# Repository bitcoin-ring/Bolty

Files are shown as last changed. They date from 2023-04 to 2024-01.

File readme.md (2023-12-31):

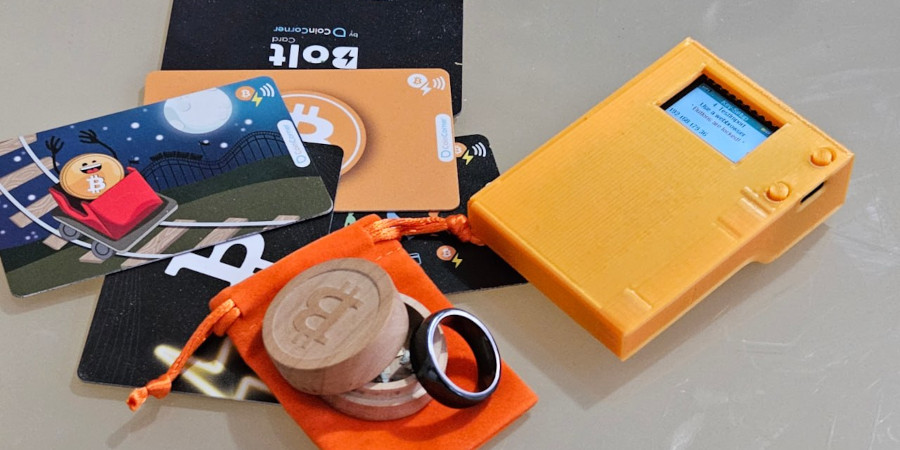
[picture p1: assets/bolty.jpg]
Bolty


# Bolty - ESP32-based BoltCard provisioning device

Bolty is an ESP32-based device with NFC capabilities designed to provision BoltCards for contactless Bitcoin Lightning Network payments. This repository contains the necessary source code, STL files for 3D printing the device enclosure, and documentation to set up and use the Bolty device.

## Features

- BoltCards provisioning for Lightning Network payments
- User-friendly web interface for device setup and management
- 3D printable enclosure design with an optional battery compartment
- Provision and deprovision BoltCards offline

## Getting Started

### Prerequisites
- LILYGO® TTGO T-Display
- An PN532 NFC module (the red square one if you want to use the enclosure),
- Basic electronics tools (e.g., soldering iron, multimeter, etc.)
- A 3D printer for printing the enclosure (optional)
- A lipo-battery (optional).

### Hardware Assembly

1. Clone this repository to your local machine:
	```shell
	git clone https://github.com/username/bolty.git
	```
2. Assemble the hardware components:

	- Solder the NFC module to the ESP32 development board.   
<table style="width: 30em;">
<tr><th>TTGO T-Display</th><th>PN532 Breakoutboard</th></tr>
<tr><td>3V</td><td>VCC</td></tr>
<tr><td>GND</td><td>GND</td></tr>
<tr><td>PIN12</td><td>MISO</td></tr>
<tr><td>PIN13</td><td>MOSI</td></tr>
<tr><td>PIN15</td><td>SS</td></tr>
<tr><td>PIN2</td><td>RSTPDN (optional)</td></tr>
<tr><td>PIN17</td><td>SCK</td></tr>
</table>
Make sure the microswitch on the NFC breakoutboard is set to SPI-configuration.

3. Navigate to the bolty/3dfiles folder and 3D print the enclosure files based on your preferences:

	- 2x Case-Button.stl
	- Case-with battery-Case.stl
	- Case-with battery-Lid.stl
	
4. Place the assembled hardware inside the 3D printed enclosure. Be careful to not put to much pressure on the tiny buttons. They rip of from the board quiet easily.

### Firmware Installation and Configuration

1. Install the required dependencies and libraries for the ESP32 development board.
	
	Arduino-IDE
	- esp32 version 1.0.6
	- Esp32 Sketch Data Upload
 	Libraries:
	- ArduinoJson version 6.20.0
	- ESPAsyncWebSrv version 1.2.6
	- Patched Adafruit_PN532_NTAG424 with ntag424 support
		from https://github.com/bitcoin-ring/Adafruit-PN532-NTAG424
	- Button2 version 1.2.0
	- qrcode version 0.0.1
	- TFT_eSPI version 2.2.20
	- ESP32-targz 1.2.0

2. Compile and upload the firmware to the ESP32 board.

3. Power on the device and wait for the display to show you a set of wifi credentials. The first startup takes a few seconds longer as the flash-memory is initialized. 
Bolty can either work in AP-mode or STA-Mode. Default is AP-Mode and the ESS-ID is always "Bolty", the password is random, also you should see an ip-adress at the bottom of the screen.

## Usage
1. Ensure your Bolty device is powered on and your computer or mobile is connected to the Wi-Fi network on the display.

2. Access the web interface of the Bolty device by navigating to the IP address displayed at the bottom part of screen using a web browser.
There are 3 menu items in the browser. Click on "SETUP" at the left side.

3. Configure your Bolty device settings.
there are multiple options.
	1. Setup a lnbit wallet, the Boltcards-extenion and a Bolt-Card configuration on a lnbits-server in one go. This is the most easiest option but it requires Bolty to be in the same wifi as your webbrowser, and your webbrowser needs a connection to the internet. Bolty will most likely have internet access in this configuration, if you dont want that use another option. Click on "SETUP"->NEW WALLET". Enter a lnbit-servers URL, enter a name for the wallet and card, modifiy the limits to your liking and present your card to the device to scan the UID of the card.
	
	2. You can import the json-string for an existing Bolt-Card created by the lnbits-Boltcards extension. This can be prepared online in a second browserwindow/tab, before you switch to the Bolty wifi. Once connected to Bolty click on "SETUP"->"IMPORT CARD". Paste the json from the prepared window into the Textarea. The button "next" turns green once the data is valid. If so click it. The name of your card and the keys should now should show up in the browser.
	3. You can also enter existing keys manually by clicking "Setup"->"EDIT CARD". Enter a Name, a the Bolt-Service url for this Bolt-Card and the keys.

4. To provision a new BoltCard, switch to the "BURN"-mode (orange). This can be done in the webbrowser or by using the lower button on the device. Now tap an NTAG424-card on the Bolty device. Make sure to keep the card presented until the process has finished. The Bolty device will write the necessary information to the NFC card, turning it into a BoltCard.

5. The BoltCard can now be used to make contactless Bitcoin Lightning Network payments with compatible payment terminals.
 
6. To wipe a BoltCard you need the corresponding keys loaded. Switch to "WIPE" mode (pink). Again, this can be done in the webbrowser or by using the lower button on the device.

## Buttons
- The upper button
	- switch on if in deepsleep mode 
	- single push switches between different card configurations. (up to five) 
	- long push toggles wifi on & off. The wifi state is saved on the eeprom, so it persist reboots.
- The lower button
	- switch between "BURN" and "WIPE"-mode. Setup is only available from the webbrowser, and if so (green upper screen) the buttons are locked.
	- long push switch off (deepsleep mode)
## Security
currently not so much, so be careful: 
 - The keys, wallet and your wifi-credentials are saved unencrypted on the eeprom of the esp32.
 - The connection between the webbrowser and Bolty is unencrypted. 
 - The backups-files you can download are unencrypted.
 - its an [esp32](https://raelize.com/blog/espressif-esp32-bypassing-encrypted-secure-boot-cve-2020-13629/)
 - anyone with a physical acccess to Bolty can produce BoltCards to spend your money

## Contributing
We welcome contributions to the Bolty project! If you'd like to contribute, please fork the repository and submit a pull request with your changes. For major changes or new features, please open an issue first to discuss your ideas with the maintainers.

## License
This project is licensed under the Apache 2.0 License. See the LICENSE file for details.

## Support and Contact
If you encounter any issues or have questions, please open an issue on GitHub.
You can also ask on https://t.me/LNBolty

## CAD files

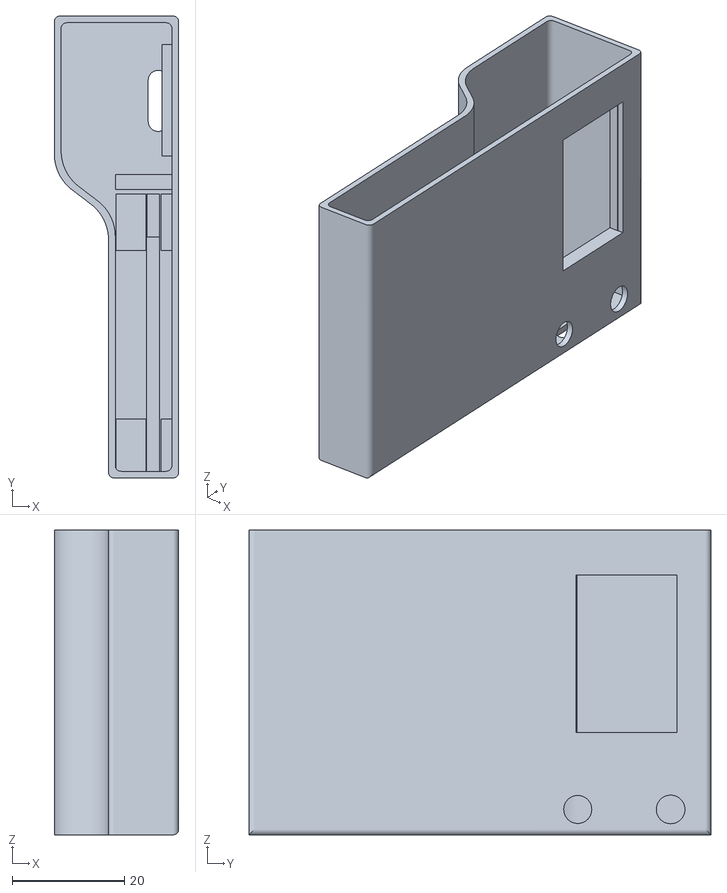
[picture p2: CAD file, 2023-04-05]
3dfiles/Case-with battery-Case.stl
22.1 x 82.2 x 54.2

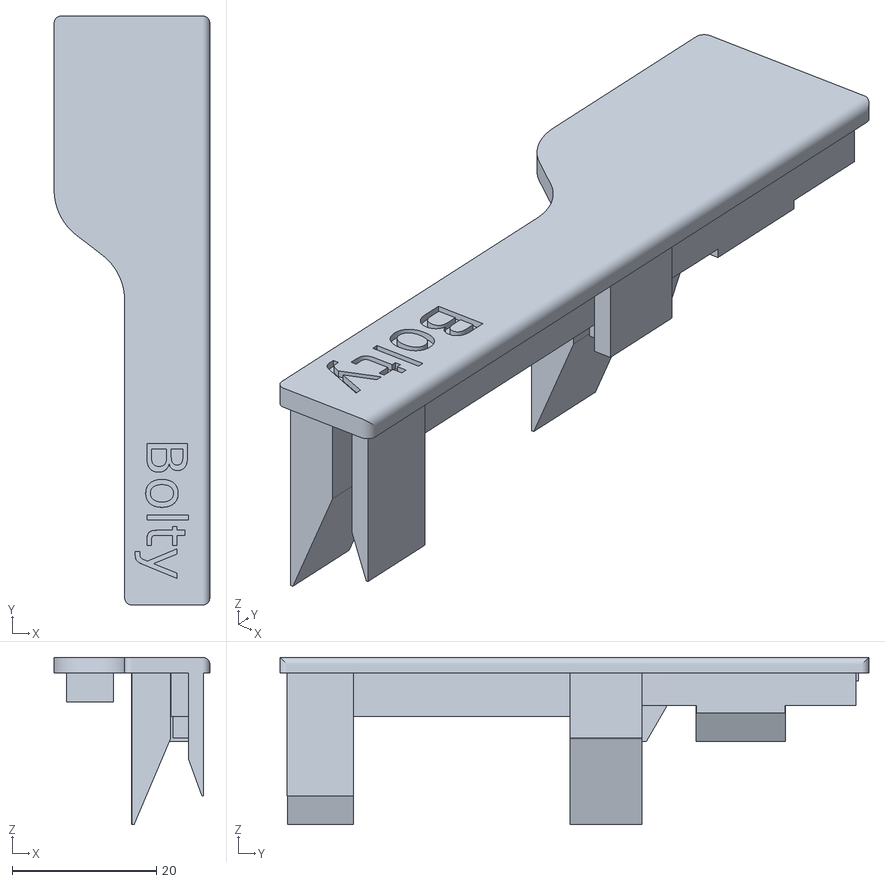
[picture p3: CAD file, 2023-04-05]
3dfiles/Case-with battery-Lid.stl
21.6 x 81.7 x 23.2

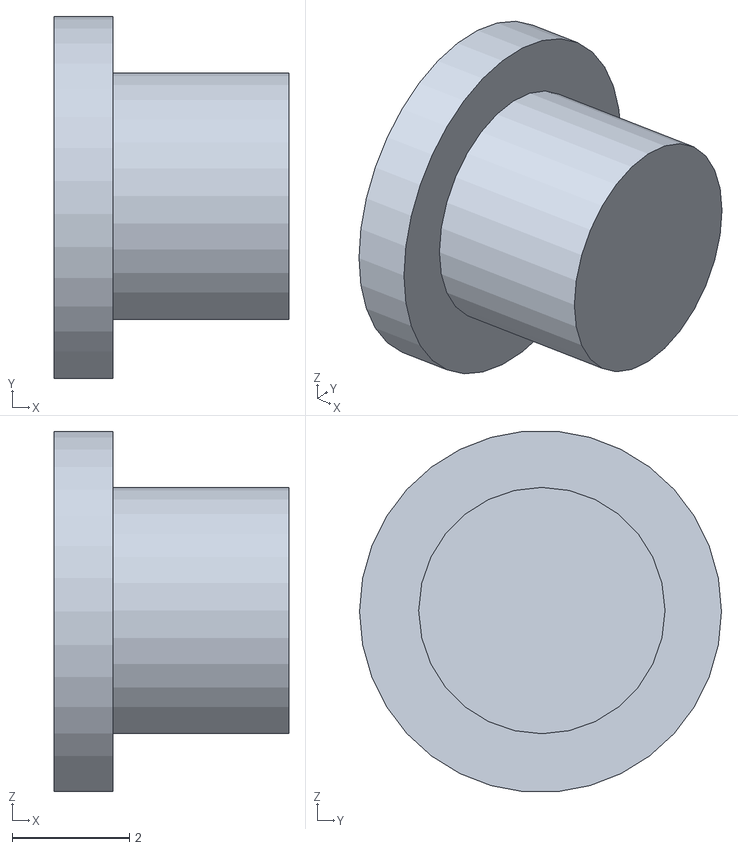
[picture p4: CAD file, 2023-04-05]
3dfiles/Case-Button.stl
4.00 x 6.17 x 6.14

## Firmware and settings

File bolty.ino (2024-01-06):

/**************************************************************************/
/*!
    @file     bolty.ino
    @author   Thilo
    https://github.com/bitcoin-ring/Bolty
    This sketch will start a wifi in AP or STA mode (WIFIMODE_*). If you want to
   use STA mode you have to enter the WIFI credentials of your existing network.
    A webserver allows to import keydata  in form of the raw json of the lnbits
   "Card key credentials" link. The keydata is saved on the eepom and should
   therefore be availabe after reboot/powerdown. The saved keydata can be used
   to provision/burn or wipe/delete ntag424 tags i.E. BoltCard, BoltRing.
    Button1:
    - śhort press: Load next boltconfiguration/keyset
    - long press: toggle wifi on/off
    Button2:
    - śhort press: Toggle between burn and wipe
    - long press: sleepmode

*/
/**************************************************************************/
#include <Arduino.h>
#include "bolt.h"
#include "gui.h"
#include <SPI.h>
#include <WiFi.h>
#include <Wire.h>
#include <esp_wifi.h>
#define DYNAMIC_JSON_DOCUMENT_SIZE 1024
#include "ArduinoJson.h"
#include "AsyncJson.h"
#include "ESPAsyncWebSrv.h"
//#include <WiFiClient.h>
#include "FS.h"
#include "SPIFFS.h"
#include <WiFiAP.h>
#define DEST_FS_USES_SPIFFS
#include <ESP32-targz.h>
#include "tarstream.h"
#include "tardata.h"

#define WIFIMODE_AP 0
#define WIFIMODE_STA 1

#define CONFIGVERSION 1

#define WIFI_AP_PASSWORD_LENGTH 8

// uncommment the next line for static wifi password
//#define WIFI_AP_PASSWORD_STATIC "wango123"

#define HTTP_CREDENTIAL_SIZE 16

//if you change this do not exceed HTTP_CREDENTIAL_SIZE-1 chars!
const char* http_default_username = "bolty";
const char* http_default_password = "bolty";

#define MAX_BOLT_DEVICES 5
char charpool[] = {
    "qweertzunopaasdfghjkyxcvbnm-?234567890QWEERTYUOPAASDFGHJKLZXCVBNM"};

// Set these to your desired credentials for WiFi AP-Mode.

char *ap_ssid = "Bolty";
#ifdef WIFI_AP_PASSWORD_STATIC
char ap_password[] = WIFI_AP_PASSWORD_STATIC;
#else
char ap_password[WIFI_AP_PASSWORD_LENGTH];
#endif

AsyncWebServer server(80);
const char *PARAM_CONFIG = "config";

// NFC Pins
#define PN532_SCK (17)
#define PN532_MOSI (13)
#define PN532_SS (15)
#define PN532_MISO (12)
#define PN532_RSTPD_N (2)
// For RSTPD_N to work i had to desolder a 10k resistor between RSTPD_N and VCC

#define APPS (3)
#define APP_KEYSETUP (0)
#define APP_BOLTBURN (1)
#define APP_BOLTWIPE (2)

#define APP_STATUS_START (0)
#define APP_STATUS_LOOP (1)
#define APP_STATUS_END (2)

BoltDevice bolt(PN532_SCK, PN532_MISO, PN532_MOSI, PN532_SS);

struct sSettings {
  char essid[33];
  char password[65];
  uint8_t wifimode;
  bool wifi_enabled;
  char http_username[HTTP_CREDENTIAL_SIZE];
  char http_password[HTTP_CREDENTIAL_SIZE];
};
sSettings mSettings;

uint8_t app_active;
int8_t app_next;
uint8_t app_status;
String SIpAddress = "Waiting for ip..";
IPAddress myIP;

uint8_t active_bolt_config;
sBoltConfig mBoltConfig;

bool signal_update_screen = false;
int signal_restart_delayed = 0;

bool bolty_hw_ready = false;

typedef void (*tAppHandler)();
typedef void (*tEvtHandler)(uint8_t btn, uint8_t evt);

struct sAppHandler {
  String app_title;
  String app_desc;
  tAppHandler app_start; // function pointer start lifecycle
  tAppHandler app_end;   // function pointer end lifecycle
  tAppHandler app_loop;  // function pointer mainloop
  uint16_t app_fgcolor;
  uint16_t app_bgcolor;
};

sAppHandler mAppHandler[APPS];

void saveSettings() {
  char path[20];
  sprintf(path, "/settings.dat");
  fs::File myFile = SPIFFS.open(path, FILE_WRITE);
  myFile.write((byte *)&mSettings, sizeof(sSettings));
  myFile.close();
}

//Extract files needed by the webserver from the data in tardata.h
void extractfiles(){
    Serial.println("Extracting files");
    Stream *HTMLTarStream = new TarStream(data_tar, (size_t) data_tar_len);
    //TarUnpacker *TARUnpacker = new TarUnpacker();
    //TARUnpacker->haltOnError(true);                                                            // stop on fail (manual restart/reset required)
    //TARUnpacker->setTarVerify(true);                                                           // true = enables health checks but slows down the overall process
    //TARUnpacker->setupFSCallbacks(targzTotalBytesFn, targzFreeBytesFn);                        // prevent the partition from exploding, recommended
    //TARGZUnpacker->setGzProgressCallback(BaseUnpacker::defaultProgressCallback ); // targzNullProgressCallback or defaultProgressCallback
    //TARUnpacker->setLoggerCallback(BaseUnpacker::targzPrintLoggerCallback);                    // gz log verbosity
    //TARUnpacker->setTarProgressCallback(BaseUnpacker::defaultProgressCallback);                // prints the untarring progress for each individual file
    //TARUnpacker->setTarStatusProgressCallback(BaseUnpacker::defaultTarStatusProgressCallback); // print the filenames as they're expanded
    //TARUnpacker->setTarMessageCallback(BaseUnpacker::targzPrintLoggerCallback);                // tar log verbosity  
    //if (!TARUnpacker->tarStreamExpander(HTMLTarStream, data_tar_len, tarGzFS, "/")){
    TarGzUnpacker *TARGZUnpacker = new TarGzUnpacker();
    TARGZUnpacker->haltOnError( true ); // stop on fail (manual restart/reset required)
    TARGZUnpacker->setTarVerify( true ); // true = enables health checks but slows down the overall process
    TARGZUnpacker->setupFSCallbacks( targzTotalBytesFn, targzFreeBytesFn ); // prevent the partition from exploding, recommended
    TARGZUnpacker->setGzProgressCallback( BaseUnpacker::defaultProgressCallback ); // targzNullProgressCallback or defaultProgressCallback
    TARGZUnpacker->setLoggerCallback( BaseUnpacker::targzPrintLoggerCallback  );    // gz log verbosity
    TARGZUnpacker->setTarProgressCallback( BaseUnpacker::defaultProgressCallback ); // prints the untarring progress for each individual file
    TARGZUnpacker->setTarStatusProgressCallback( BaseUnpacker::defaultTarStatusProgressCallback ); // print the filenames as they're expanded
    TARGZUnpacker->setTarMessageCallback( BaseUnpacker::targzPrintLoggerCallback ); // tar log verbosity
    if( !TARGZUnpacker->tarGzStreamExpander( HTMLTarStream, tarGzFS ) ) {
      Serial.println("Error while unpacking the webserver files");
      return;
    }
    //write version info
    fs::File myFile = SPIFFS.open("/fsversion.dat", FILE_WRITE);
    myFile.write((byte *) &fsversion, sizeof(fsversion));
    myFile.close();

    Serial.println("done!");
    
}

int checkFsVersion(){
  int myversion = -1;
  fs::File myFile = SPIFFS.open("/fsversion.dat", FILE_READ);
  myFile.read((byte *) &myversion, sizeof(myversion));
  myFile.close();
  Serial.println(myversion);
  return myversion;
}

void loadSettings() {
  char path[20];
  sprintf(path, "/settings.dat");
  Serial.print(path);
  if (SPIFFS.exists(path) == 1) {
    Serial.println(" found");
    fs::File myFile = SPIFFS.open(path, FILE_READ);
    myFile.read((byte *)&mSettings, sizeof(sSettings));
    myFile.close();
  } else {
    Serial.println(" not found");
    mSettings.essid[0] = 0;
    mSettings.password[0] = 0;
    mSettings.wifimode = WIFIMODE_AP;
    mSettings.wifi_enabled = 1;
    memcpy(mSettings.http_username, http_default_username, HTTP_CREDENTIAL_SIZE);
    memcpy(mSettings.http_password, http_default_password, HTTP_CREDENTIAL_SIZE);
  }
  dumpsettings();
}

void saveBoltConfig(uint8_t slot) {
  char path[20];
  sprintf(path, "/config%02x.dat", slot);
  fs::File myFile = SPIFFS.open(path, FILE_WRITE);
  myFile.write((byte *)&mBoltConfig, sizeof(sBoltConfig));
  myFile.close();
}

/*
uint8_t boltconfig_key[] = {0x00, 0x00, 0x00, 0x00, 0x00, 0x00, 0x00, 0x00,
0x00, 0x00, 0x00, 0x00, 0x00, 0x00, 0x00, 0x00}; uint8_t newlen =
bolt.nfc->ntag424_addpadding(strlen(mBoltConfig.url), 16,  (uint8_t *)
&mBoltConfig.url); Serial.println(bolt.nfc->ntag424_encrypt(boltconfig_key,
newlen, (uint8_t *) &mBoltConfig.url, testurl_enc));
Serial.println(bolt.nfc->ntag424_decrypt(boltconfig_key, newlen, testurl_enc,
testurl)); bolt.nfc->PrintHexChar(testurl, 56);
*/

void loadBoltConfig(uint8_t slot) {
  char path[20];
  sprintf(path, "/config%02x.dat", slot);
  Serial.print(path);
  Serial.println(sizeof(((sBoltConfig *)0)->url));
  memset(&mBoltConfig, 0, sizeof(sBoltConfig));
  uint8_t testurl_enc[sizeof(((sBoltConfig *)0)->url)];
  uint8_t testurl[sizeof(((sBoltConfig *)0)->url)];
  if (SPIFFS.exists(path) == 1) {
    Serial.println(" found");
    fs::File myFile = SPIFFS.open(path, FILE_READ);
    myFile.read((byte *)&mBoltConfig, sizeof(sBoltConfig));
    myFile.close();
  } else {
    Serial.println(" not found");
    strcpy(mBoltConfig.card_name, "*new*");
    mBoltConfig.url[0] = 0;
    mBoltConfig.uid[0] = 0;
    mBoltConfig.k0[0] = 0;
    mBoltConfig.k1[0] = 0;
    mBoltConfig.k2[0] = 0;
    mBoltConfig.k3[0] = 0;
    mBoltConfig.k4[0] = 0;
    mBoltConfig.wallet_name[0] = 0;
    mBoltConfig.wallet_url[0] = 0;
    mBoltConfig.wallet_host[0] = 0;
  }
  dumpconfig();
}

String exportBoltConfig() {
  String path = "/backup.dat";
  SPIFFS.remove(path);
  fs::File myFile = SPIFFS.open(path, FILE_APPEND);
  for (uint8_t i = 0; i < MAX_BOLT_DEVICES; i++) {
    loadBoltConfig(i);
    myFile.write((byte *)&mBoltConfig, sizeof(sBoltConfig));
  }
  myFile.close();
  loadBoltConfig(active_bolt_config);
  return path;
}

void importBoltConfig() {
  String path = "/backup.dat";
  fs::File myFile = SPIFFS.open(path, FILE_READ);
  for (uint8_t i = 0; i < MAX_BOLT_DEVICES; i++) {
    myFile.seek(i * sizeof(sBoltConfig));
    myFile.readBytes((char *)&mBoltConfig, sizeof(sBoltConfig));
    // loadBoltConfig(i);
    saveBoltConfig(i);
    dumpconfig();
  }
  myFile.close();
  loadBoltConfig(active_bolt_config);
}

// Keysetup
void app_keysetup_start() { Serial.println("app_KEYSETUP_start"); }

long lasttime = 0;
String default_app_message = "* Buttons are locked! *";
String app_message = default_app_message;
void app_keysetup_loop() {
  if ((millis() - lasttime) > 200) {
    lasttime = millis();
    tft.setFreeFont(&FreeSans9pt7b);
    tft.setTextColor(APPRED);
    if (bolty_hw_ready){
      bool success = bolt.scanUID();
      app_message = bolt.getScannedUid();
    }
    if (app_message == "") {
      app_message = default_app_message;
    }
    tft.fillRect(0, -3 + (3 * 23), tft.width(), 21, APPWHITE);
    displayTextCentered(-3 + (4 * 21), app_message);
  }
  if (!mSettings.wifi_enabled) {
    app_next = APP_BOLTBURN;
  }
  delay(50);
}

String web_keysetup_processor(const String &var) {
  // Serial.println("web_keysetup_loop");
  if (var == "wallet_name")
    return mBoltConfig.wallet_name;
  if (var == "wallet_host")
    return mBoltConfig.wallet_host;
  if (var == "wallet_url")
    return mBoltConfig.wallet_url;
  if (var == "wallet_link")
    return mBoltConfig.wallet_url;
  if (var == "uid")
    return mBoltConfig.uid;
  return processor_default(var);
}

void app_keysetup_end() { Serial.println("app_KEYSETUP_end"); }

// Ringsetup
void APP_BOLTBURN_start() { Serial.println("APP_BOLTBURN_start"); }

uint32_t previousMillis;
uint32_t Interval = 100;

void APP_BOLTBURN_loop() {
  // Serial.println("APP_BOLTBURN_loop");
  // set the keys
  if (millis() - previousMillis < Interval) {
    return;
  }
  previousMillis = millis();
  Interval = 100;
  if (bolty_hw_ready){
    bolt.setDefautKeysCur();
    bolt.setNewKey(mBoltConfig.k0, 0);
    bolt.setNewKey(mBoltConfig.k1, 1);
    bolt.setNewKey(mBoltConfig.k2, 2);
    bolt.setNewKey(mBoltConfig.k3, 3);
    bolt.setNewKey(mBoltConfig.k4, 4);
    String lnurl = String(mBoltConfig.url);
    uint8_t burn_result = bolt.burn(lnurl);
    if (burn_result != JOBSTATUS_WAITING) {
      previousMillis = millis();
      Interval = 3000;
      dumpconfig();
    }
  }
  else{
    tft.setFreeFont(&FreeSans9pt7b);
    tft.setTextColor(APPRED);
    tft.fillRect(0, -3 + (3 * 23), tft.width(), 21, APPWHITE);
    displayTextCentered(-3 + (4 * 21), "nfc hw not ready");
  }
}


String shortenkeys(const String &var){
  return var.substring(0,3) + "*************";
}

String processor_default(const String &var){
  if (var == "cnn")
    return String(active_bolt_config + 1).c_str();
  if (var == "cn")
    return mBoltConfig.card_name;
  if (var == "url")
    return mBoltConfig.url;
  if (var == "ks0")
    return shortenkeys(mBoltConfig.k0);
  if (var == "ks1")
    return shortenkeys(mBoltConfig.k1);
  if (var == "ks2")
    return shortenkeys(mBoltConfig.k2);
  if (var == "ks3")
    return shortenkeys(mBoltConfig.k3);
  if (var == "ks4")
    return shortenkeys(mBoltConfig.k4);
  if (var == "k0")
    return mBoltConfig.k0;
  if (var == "k1")
    return mBoltConfig.k1;
  if (var == "k2")
    return mBoltConfig.k2;
  if (var == "k3")
    return mBoltConfig.k3;
  if (var == "k4")
    return mBoltConfig.k4;
  if (var == "wifista")
        return String(mSettings.wifimode);
  if (var == "essid")
        if (mSettings.wifimode == WIFIMODE_STA)
                return String(mSettings.essid);
  /*if (var == "essid")
    //if (mSettings.wifimode == WIFIMODE_STA)
    return String(mSettings.essid);
   */
  return String();
}

String web_burn_processor(const String &var) {
  Serial.println("web_ringsetup_loop");
  if (var == "job")
    return "Burn";
  return processor_default(var);
}
void APP_BOLTBURN_end() { Serial.println("APP_BOLTBURN_end"); }
// Ringsetup
void APP_BOLTWIPE_start() { Serial.println("APP_BOLTWIPE_start"); }

void APP_BOLTWIPE_loop() {
  // Serial.println("APP_BOLTWIPE_loop");
  if (millis() - previousMillis < Interval) {
    return;
  }
  previousMillis = millis();
  Interval = 100;
  if (bolty_hw_ready){
    bolt.setDefautKeysNew();
    bolt.setCurKey(mBoltConfig.k0, 0);
    bolt.setCurKey(mBoltConfig.k1, 1);
    bolt.setCurKey(mBoltConfig.k2, 2);
    bolt.setCurKey(mBoltConfig.k3, 3);
    bolt.setCurKey(mBoltConfig.k4, 4);
    uint8_t wipe_result = bolt.wipe();
    if (wipe_result != JOBSTATUS_WAITING) {
      previousMillis = millis();
      Interval = 3000;
      dumpconfig();
    }
  }
  else{
    tft.setFreeFont(&FreeSans9pt7b);
    tft.setTextColor(APPRED);
    tft.fillRect(0, -3 + (3 * 23), tft.width(), 21, APPWHITE);
    displayTextCentered(-3 + (4 * 21), "nfc hw not ready");
  }
}

String web_ringwipe_processor(const String &var) {
  Serial.println("web_ringwipe_loop");
  if (var == "job")
    return "Wipe";
  return processor_default(var);
}
void APP_BOLTWIPE_end() { Serial.println("APP_BOLTWIPE_end"); }

uint8_t lineh = 21;
void update_screen() {
  tft.fillScreen(fromrgb(0xed, 0xef, 0xf2));
  int8_t ofs = -3;
  tft.fillRect(0, 0, tft.width(), 23, mAppHandler[app_active].app_bgcolor);
  draw_battery(true);
  draw_wifi(mSettings.wifi_enabled);

  tft.setFreeFont(&FreeSans9pt7b);
  tft.setTextColor(APPWHITE);
  displayTextCentered(ofs + (1 * lineh), mAppHandler[app_active].app_title);
  tft.setTextColor(mAppHandler[app_active].app_fgcolor);
  displayTextCentered(ofs + (2 * lineh), String(active_bolt_config + 1) + ". " +
                                             mBoltConfig.card_name);
  displayTextCentered(ofs + (3 * lineh), mAppHandler[app_active].app_desc);
  if (mSettings.wifi_enabled) {
    // displayTextLeft(ofs + (4 * lineh), "WiFi");
    if (mSettings.wifimode == WIFIMODE_AP) {
      displayTextLeft(ofs + (5 * lineh),
                      "WiFi " + String(ap_ssid) + ":" + String(ap_password));
    }
    SIpAddress = getIpAddress();
    displayTextLeft(ofs + (6 * lineh), SIpAddress);
  }
  signal_update_screen = false;
}

void handle_events() {
  // Button 0 short clicky = next keyset
  if ((sharedvars.appbuttons[0] == 1) && (app_active != APP_KEYSETUP)) {
    // we dont want to interrupt anything done with keyysetup
    active_bolt_config += 1;
    if (active_bolt_config >= MAX_BOLT_DEVICES) {
      active_bolt_config = 0;
    }
    loadBoltConfig(active_bolt_config);
    signal_update_screen = true;
  }
  // Button 1 short clicky = next app
  if ((sharedvars.appbuttons[1] == 1) && (app_active != APP_KEYSETUP)) {
    // we dont want to interrupt anything done with keyysetup
    app_next = app_active + 1;
    if (app_next > APPS - 1) {
      app_next = 1;
    }
  }
  // Button 0 long clicky =
  if (sharedvars.appbuttons[0] == 2) {
    wifi_toogle();
    signal_update_screen = true;
  }
  // Button 1 long clicky =
  if (sharedvars.appbuttons[1] == 2) {
    nfc_stop();
    esp_sleep_enable_ext0_wakeup(GPIO_NUM_35, 0); // 1 = High, 0 = Low
    esp_deep_sleep_start();
  }
  // Button 0 double clicky =
  if (sharedvars.appbuttons[0] == 3) {
    Serial.println("double click btn0");
    String wurl =
        String(mBoltConfig.wallet_host) + "?" + String(mBoltConfig.wallet_url);
    Serial.println(wurl);
    // displayQR(wurl);
  }
  // Button 1 duoble clicky =
  if (sharedvars.appbuttons[1] == 3) {
    Serial.println("double click btn1");
  }
  // reset button events
  sharedvars.appbuttons[0] = 0;
  sharedvars.appbuttons[1] = 0;
}

void app_stateengine() {
  handle_events();
  if (signal_update_screen){
      update_screen();
  }
  if (signal_restart_delayed > 0){
    delay(3000);
    ESP.restart();
  }
  if (app_next >= APPS)
    app_next = 0;
  // do not switch to keysetup using buttons
  if (app_next < 0)
    app_next = APPS - 1;

  if (app_active != app_next) {
    Serial.print("start: current app:");
    Serial.println(app_active);
    Serial.print("switching to app:");
    Serial.println(app_next);
    app_status = APP_STATUS_END;
  }
  if (app_status == APP_STATUS_START) {
    (*mAppHandler[app_active].app_start)();
    app_status = APP_STATUS_LOOP;
    update_screen();
  }
  if (app_status == APP_STATUS_LOOP) {
    draw_battery();
    draw_wifi(mSettings.wifi_enabled);
    (*mAppHandler[app_active].app_loop)();
  }
  if (app_status == APP_STATUS_END) {
    Serial.print("end: ending app:");
    Serial.println(app_active);
    Serial.print("end: activating app:");
    Serial.println(app_next);
    (*mAppHandler[app_active].app_end)();
    app_active = app_next;
    app_status = APP_STATUS_START;
  }
}

void dumpconfig() {
  Serial.println(mBoltConfig.wallet_name);
  Serial.println(mBoltConfig.wallet_host);
  Serial.println(mBoltConfig.wallet_url);
  Serial.println(mBoltConfig.uid);
  Serial.println(mBoltConfig.card_name);
  Serial.println(mBoltConfig.url);
  Serial.println(mBoltConfig.k0);
  Serial.println(mBoltConfig.k1);
  Serial.println(mBoltConfig.k2);
  Serial.println(mBoltConfig.k3);
  Serial.println(mBoltConfig.k4);
}

void dumpsettings() {
  Serial.println(mSettings.wifimode);
  Serial.println(mSettings.essid);
  Serial.println(mSettings.password);
  Serial.println(mSettings.wifi_enabled);
  Serial.println(mSettings.http_username);
  Serial.println(mSettings.http_password);
}

void checkparams(AsyncWebServerRequest *request) {
  if (request->hasParam("d")) {
    AsyncWebParameter *p = request->getParam("d");
    Serial.println("got d param");
    Serial.println(p->value().c_str());
    if (p->value() == "p") {
      active_bolt_config =
          constrain((active_bolt_config - 1), 0, MAX_BOLT_DEVICES - 1);
    }
    if (p->value() == "n") {
      active_bolt_config =
          constrain((active_bolt_config + 1), 0, MAX_BOLT_DEVICES - 1);
    }
    loadBoltConfig(active_bolt_config);
    signal_update_screen = true;
  }
  Serial.println(active_bolt_config);
}

void empty() {
  //
}

void randomchar(char *outbuf, uint8_t count) {
  for (uint8_t i = 0; i < count; i++) {
    Serial.print(i);
    Serial.print(":");
    outbuf[i] = charpool[random(0, 63)];
    Serial.println(outbuf[i]);
  }
  outbuf[count] = 0;
}

String getIpAddress() {
  if (mSettings.wifimode == WIFIMODE_AP)
    myIP = WiFi.softAPIP();
  if (mSettings.wifimode == WIFIMODE_STA)
    myIP = WiFi.localIP();
  return myIP.toString();
}

void wifi_start() {
  // if we have credentials try connecting. WIFIMODE_STA will fallback to
  // mSettings.wifimode == WIFIMODE_AP
  if ((mSettings.essid != "") && (mSettings.password != "")) {
    mSettings.wifimode = WIFIMODE_STA;
  }
  if (mSettings.wifimode == WIFIMODE_AP) {
#ifndef WIFI_AP_PASSWORD_STATIC
    randomchar(ap_password, sizeof(ap_password));
#endif
    WiFi.softAP(ap_ssid, ap_password);
    myIP = WiFi.softAPIP();
  }

  uint8_t connect_count = 0;
  if (mSettings.wifimode == WIFIMODE_STA) {
    WiFi.begin(mSettings.essid, mSettings.password);
    while (WiFi.status() != WL_CONNECTED) {
      delay(500);
      connect_count++;
      Serial.println("Connecting to WiFi..");
      // fall back to AP mode if we cannot connect for 10 seconds
      if (connect_count > 10) {
        Serial.println("Cannot connect to Network. Fallback to AP-Mode.");
        wifi_stop();
        delay(50);
        mSettings.wifimode = WIFIMODE_AP;
#ifndef WIFI_AP_PASSWORD_STATIC
        randomchar(ap_password, sizeof(ap_password));
#endif
        WiFi.softAP(ap_ssid, ap_password);
        myIP = WiFi.softAPIP();
        break;
      }
    }
    // still STA mode? then we should be connected by now!
    if (mSettings.wifimode == WIFIMODE_STA) {
      myIP = WiFi.localIP();
    }
  }
  if (!mSettings.wifi_enabled) {
    mSettings.wifi_enabled = true;
    saveSettings();
    //set wifimode  after savesettings. we dont want to persist it if we fallback to apmode.
    if ((mSettings.wifimode == WIFIMODE_STA) && (connect_count <= 10)) {
      mSettings.wifimode = WIFIMODE_AP;
    }
  }
  server.begin();
}

void wifi_stop() {
  server.end();
  WiFi.mode(WIFI_STA);
  WiFi.disconnect();
  esp_wifi_stop();
  Serial.println("WIFI: Disconnected");
  delay(100);
  WiFi.mode(WIFI_OFF);
  delay(100);
  if (mSettings.wifi_enabled) {
    mSettings.wifi_enabled = false;
    saveSettings();
  }
}

void wifi_toogle() {
  if (mSettings.wifi_enabled) {
    wifi_stop();
  } else {
    wifi_start();
  }
}

void nfc_start() {
  Serial.println("switching nfc on");
  digitalWrite(PN532_RSTPD_N, HIGH);
}
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
void loop(void) {

  app_stateengine();

  delay(100);
}

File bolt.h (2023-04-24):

#ifndef BOLT_H
#define BOLT_H

//#define NTAG424DEBUG

#include "gui.h"
#include <Adafruit_PN532_NTAG424.h>
#include <SPI.h>
#include <Wire.h>

#define JOBSTATUS_IDLE 0
#define JOBSTATUS_WAITING 1
#define JOBSTATUS_PROVISIONING 2
#define JOBSTATUS_WIPING 3
#define JOBSTATUS_DONE 4
#define JOBSTATUS_ERROR 5

String boltstatustext[6] = {
    "idle",          "waiting for nfc-tag..",  "provisioning data..",
    "wiping data..", "done - remove the card", "error",
};

struct sBoltConfig {
  char card_name[50];
  char wallet_host[50];
  char wallet_name[256];
  char wallet_url[256];
  char url[256];
  char uid[17];
  char k0[33];
  char k1[33];
  char k2[33];
  char k3[33];
  char k4[33];
};

String convertIntToHex(uint8_t *input, uint8_t len) {
  String ret = "";
  for (uint8_t i = 0; i < len; i++) {
    char hexChar[2];
    sprintf(hexChar, "%02X", input[i]);
    ret += hexChar;
  }
  return ret;
}

uint8_t convertCharToHex(char ch) {
  uint8_t returnType;
  switch (toupper(ch)) {
  case '0':
    returnType = 0;
    break;
  case '1':
    returnType = 1;
    break;
  case '2':
    returnType = 2;
    break;
  case '3':
    returnType = 3;
    break;
  case '4':
    returnType = 4;
    break;
  case '5':
    returnType = 5;
    break;
  case '6':
    returnType = 6;
    break;
  case '7':
    returnType = 7;
    break;
  case '8':
    returnType = 8;
    break;
  case '9':
    returnType = 9;
    break;
  case 'A':
    returnType = 10;
    break;
  case 'B':
    returnType = 11;
    break;
  case 'C':
    returnType = 12;
    break;
  case 'D':
    returnType = 13;
    break;
  case 'E':
    returnType = 14;
    break;
  case 'F':
    returnType = 15;
    break;
  default:
    returnType = 0;
    break;
  }
  return returnType;
}

class BoltDevice {

public: // Access specifier
  Adafruit_PN532 *nfc = NULL;
  uint8_t key_cur[5][16] = {{0x00, 0x00, 0x00, 0x00, 0x00, 0x00, 0x00, 0x00,
                             0x00, 0x00, 0x00, 0x00, 0x00, 0x00, 0x00, 0x00},
                            {0x00, 0x00, 0x00, 0x00, 0x00, 0x00, 0x00, 0x00,
                             0x00, 0x00, 0x00, 0x00, 0x00, 0x00, 0x00, 0x00},
                            {0x00, 0x00, 0x00, 0x00, 0x00, 0x00, 0x00, 0x00,
                             0x00, 0x00, 0x00, 0x00, 0x00, 0x00, 0x00, 0x00},
                            {0x00, 0x00, 0x00, 0x00, 0x00, 0x00, 0x00, 0x00,
                             0x00, 0x00, 0x00, 0x00, 0x00, 0x00, 0x00, 0x00},
                            {0x00, 0x00, 0x00, 0x00, 0x00, 0x00, 0x00, 0x00,
                             0x00, 0x00, 0x00, 0x00, 0x00, 0x00, 0x00, 0x00}};
  uint8_t key_new[5][16] = {{0x00, 0x00, 0x00, 0x00, 0x00, 0x00, 0x00, 0x00,
                             0x00, 0x00, 0x00, 0x00, 0x00, 0x00, 0x00, 0x00},
                            {0x00, 0x00, 0x00, 0x00, 0x00, 0x00, 0x00, 0x00,
                             0x00, 0x00, 0x00, 0x00, 0x00, 0x00, 0x00, 0x00},
                            {0x00, 0x00, 0x00, 0x00, 0x00, 0x00, 0x00, 0x00,
                             0x00, 0x00, 0x00, 0x00, 0x00, 0x00, 0x00, 0x00},
                            {0x00, 0x00, 0x00, 0x00, 0x00, 0x00, 0x00, 0x00,
                             0x00, 0x00, 0x00, 0x00, 0x00, 0x00, 0x00, 0x00},
                            {0x00, 0x00, 0x00, 0x00, 0x00, 0x00, 0x00, 0x00,
                             0x00, 0x00, 0x00, 0x00, 0x00, 0x00, 0x00, 0x00}};

  uint8_t job_status; // 0=idle; 1=wait for tag; 2=busy provisioning;3=busy wipe
  uint8_t job_perc;
  uint8_t job_ok;
  String last_scanned_uid;

  BoltDevice(uint8_t SCK, uint8_t MISO, uint8_t MOSI,
             uint8_t SS) { // Constructor
    nfc = new Adafruit_PN532(SCK, MISO, MOSI, SS);
  }

  void setDefautKeys(uint8_t keys[5][16]) {
    for (int i = 0; i < 5; i++) {
      memset((void *)(keys[i]), 0, 16);
    }
  }

  void setDefautKeysNew() { setDefautKeys(key_new); }
  void setDefautKeysCur() { setDefautKeys(key_cur); }

  void setKey(uint8_t keys[16], String key) {
    for (int i = 0; i < key.length(); i += 2) {
      uint8_t ki = (i / 2);
      uint8_t upper = (convertCharToHex(key[i]) << 4);
      uint8_t lower = (convertCharToHex(key[i + 1]));
      keys[ki] = (upper | lower);
    }
    // Serial.print("Key Set: ");
    // Serial.println(key);
  }

  void setNewKey(String key, uint8_t keyno) { setKey(key_new[keyno], key); }

  void setCurKey(String key, uint8_t keyno) { setKey(key_cur[keyno], key); }

  bool begin() {

    nfc->begin();

    uint32_t versiondata = nfc->getFirmwareVersion();
    if (!versiondata) {
      Serial.print("Didn't find PN53x board");
      return false;
        ; // halt
    }
    // Got ok data, print it out!
    Serial.print("Found chip PN53x");
    Serial.println((versiondata >> 24) & 0xFF, HEX);
    Serial.print("Firmware ver. ");
    Serial.print((versiondata >> 16) & 0xFF, DEC);
    Serial.print('.');
    Serial.println((versiondata >> 8) & 0xFF, DEC);

    // configure board to read RFID tags
    nfc->SAMConfig();

    Serial.println("NFC Ready...");
    return true;
  }

  String get_job_status() { return boltstatustext[job_status]; }

  uint8_t get_job_perc() { return job_perc; }

  uint8_t get_job_status_id() { return job_status; }

  void set_job_status_id(uint8_t new_status) {
    job_status = new_status;
    uint16_t statcolor = APPBLACK;
    if (job_status == JOBSTATUS_ERROR) {
      statcolor = APPRED;

    } else if (job_status == JOBSTATUS_WIPING) {
      statcolor = APPORANGE;
    } else if (job_status == JOBSTATUS_PROVISIONING) {
      statcolor = APPORANGE;
    } else if (job_status == JOBSTATUS_DONE) {
      statcolor = APPGREEN;
    }
    tft.setFreeFont(&FreeSans9pt7b);
    tft.setTextColor(APPWHITE);
    tft.fillRect(0, -3 + (3 * 23), tft.width(), 21, statcolor);
    displayTextCentered(-3 + (4 * 21), get_job_status());
    tft.setTextColor(APPBLACK);
  }

  long lastscan = 0;

  bool scanUID() {
    uint8_t success;
    uint8_t uid[] = {0, 0, 0, 0, 0, 0,
                     0, 0, 0, 0, 0, 0}; // Buffer to store the returned UID
    uint8_t uidLength; // Length of the UID (4 or 7 bytes depending on ISO14443A
                       // card type)
    if ((millis() - lastscan) > 2000) {
      last_scanned_uid = "";
    };
    // Wait for an NTAG203 card.  When one is found 'uid' will be populated with
    // the UID, and uidLength will indicate the size of the UUID (normally 7)
    success =
        nfc->readPassiveTargetID(PN532_MIFARE_ISO14443A, uid, &uidLength, 100);
    if (success) {
      nfc->PrintHex(uid, uidLength);
      if (((uidLength == 7) || (uidLength == 4)) &&
          (nfc->ntag424_isNTAG424())) {
        lastscan = millis();
        last_scanned_uid = convertIntToHex(uid, uidLength);
        return true;
      }
    }
    return false;
  }

  String getScannedUid() { return last_scanned_uid; }
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

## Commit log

2023-04-09 Naming is more consistent now. Cardkeys are now shortened in info view
    [bolty.ino, gui.h]
2023-04-13 added wiring instructions
2023-04-23 fixes tft not in sync with config when configuration is loaded from browser
    [bolty.ino]
2023-04-24 allows startup if nfc hardware initiaization fails
    [bolt.h, bolty.ino]
2023-12-30 readme.md change: remove "Esp32 Sketch Data Upload" from installation
